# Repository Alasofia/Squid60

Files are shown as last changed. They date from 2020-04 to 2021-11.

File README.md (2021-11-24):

# Squid60
GH60 Compatible PCB using Hi-Tek 725 Series (Space Invaders) switches.

Supports 8255C+/RT101 layouts.

Thanks to Engicoder and ai03 for the footprints and PCB design guide.

# Pictures
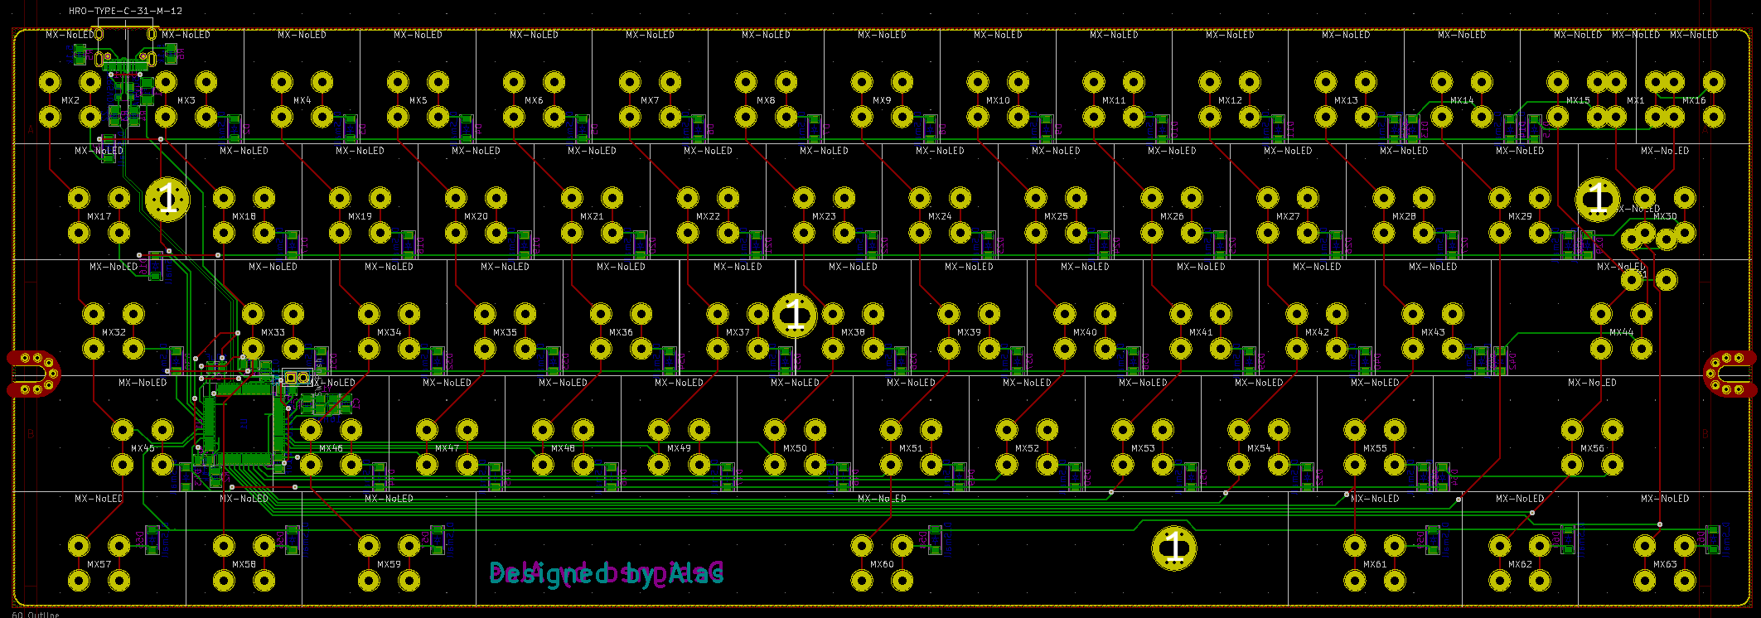
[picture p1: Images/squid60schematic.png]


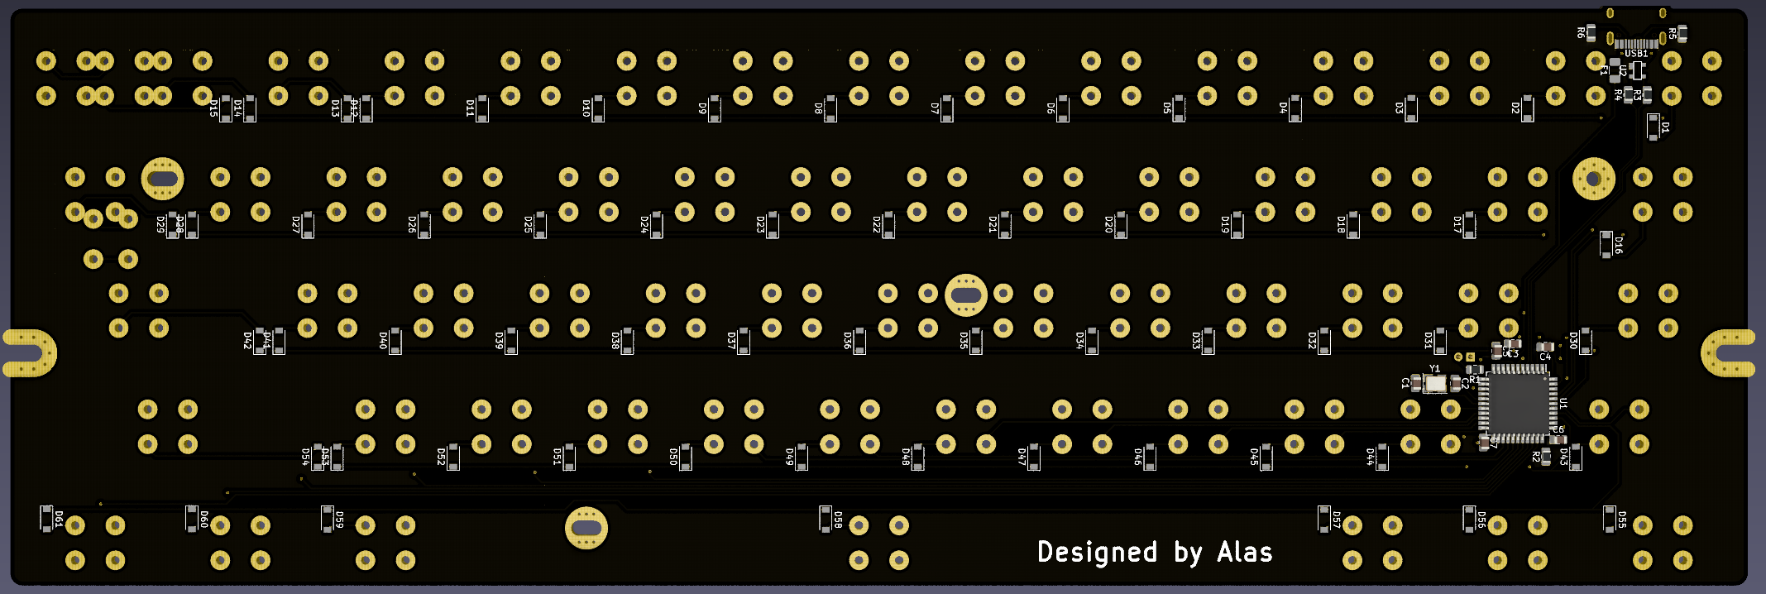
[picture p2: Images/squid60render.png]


This work is licensed under the Creative Commons Attribution-NonCommercial 4.0 International License.

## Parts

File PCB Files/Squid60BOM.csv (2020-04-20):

Id | Designator | Package | Quantity | Designation | Supplier and ref
1 | REF** | 60_Outline-Modded | 1 | 60_Outline
2 | SW1 | PinSocket_1x02_P2.00mm_Vertical | 1 | SW_Push
3 | Y1 | Crystal_SMD_3225-4Pin_3.2x2.5mm | 1 | 16Mhz
4 | F1 | Fuse_1206_3216Metric | 1 | 500mA
5 | C7,C6,C5 | C_0805_2012Metric | 3 | 0.1uF
6 | C4 | C_0805_2012Metric | 1 | 10uF
7 | C3 | C_0805_2012Metric | 1 | 1uF
8 | C2,C1 | C_0805_2012Metric | 2 | 22pF
9 | R6,R5 | R_0805_2012Metric | 2 | 5.1k
10 | R4,R3 | R_0805_2012Metric | 2 | 22
11 | R2 | R_0805_2012Metric | 1 | 1k
12 | R1 | R_0805_2012Metric | 1 | 10k
13 | U1 | TQFP-44_10x10mm_P0.8mm | 1 | ATmega32U4-AU
14 | MX44,MX45 | Hitek725-2.25U | 2 | MX-NoLED
15 | MX63,MX61,MX59,MX57,MX30,MX17 | Hitek725-1.5U | 6 | MX-NoLED
16 | MX62,MX58,MX55,MX54,MX53,MX52,MX51,MX50,MX49,MX48,MX47,MX46,MX43,MX42,MX41,MX40,MX39,MX38,MX37,MX36,MX35,MX34,MX33,MX29,MX28,MX27,MX26,MX25,MX24,MX23,MX22,MX21,MX20,MX19,MX18,MX16,MX15,MX14,MX13,MX12,MX11,MX10,MX9,MX8,MX7,MX6,MX5,MX4,MX3,MX2 | Hitek725-1U | 50 | MX-NoLED
17 | USB1 | HRO-TYPE-C-31-M-12-Assembly | 1 | HRO-TYPE-C-31-M-12
18 | U2 | SOT143B | 1 | PRTR5V0U2X
19 | MX31 | Hitek725-BigAssEnter | 1 | MX-NoLED
20 | MX1 | Hitek725-2U | 1 | MX-NoLED
21 | MX60 | Hitek725-7U | 1 | MX-NoLED
22 | MX56 | Hitek725-2.75U | 1 | MX-NoLED
23 | MX32 | Hitek725-1.75U | 1 | MX-NoLED
24 | D61,D60,D59,D58,D57,D56,D55,D54,D53,D52,D51,D50,D49,D48,D47,D46,D45,D44,D43,D42,D41,D40,D39,D38,D37,D36,D35,D34,D33,D32,D31,D30,D29,D28,D27,D26,D25,D24,D23,D22,D21,D20,D19,D18,D17,D16,D15,D14,D13,D12,D11,D10,D9,D8,D7,D6,D5,D4,D3,D2,D1 | D_SOD-123-Pretty | 61 | D_Small

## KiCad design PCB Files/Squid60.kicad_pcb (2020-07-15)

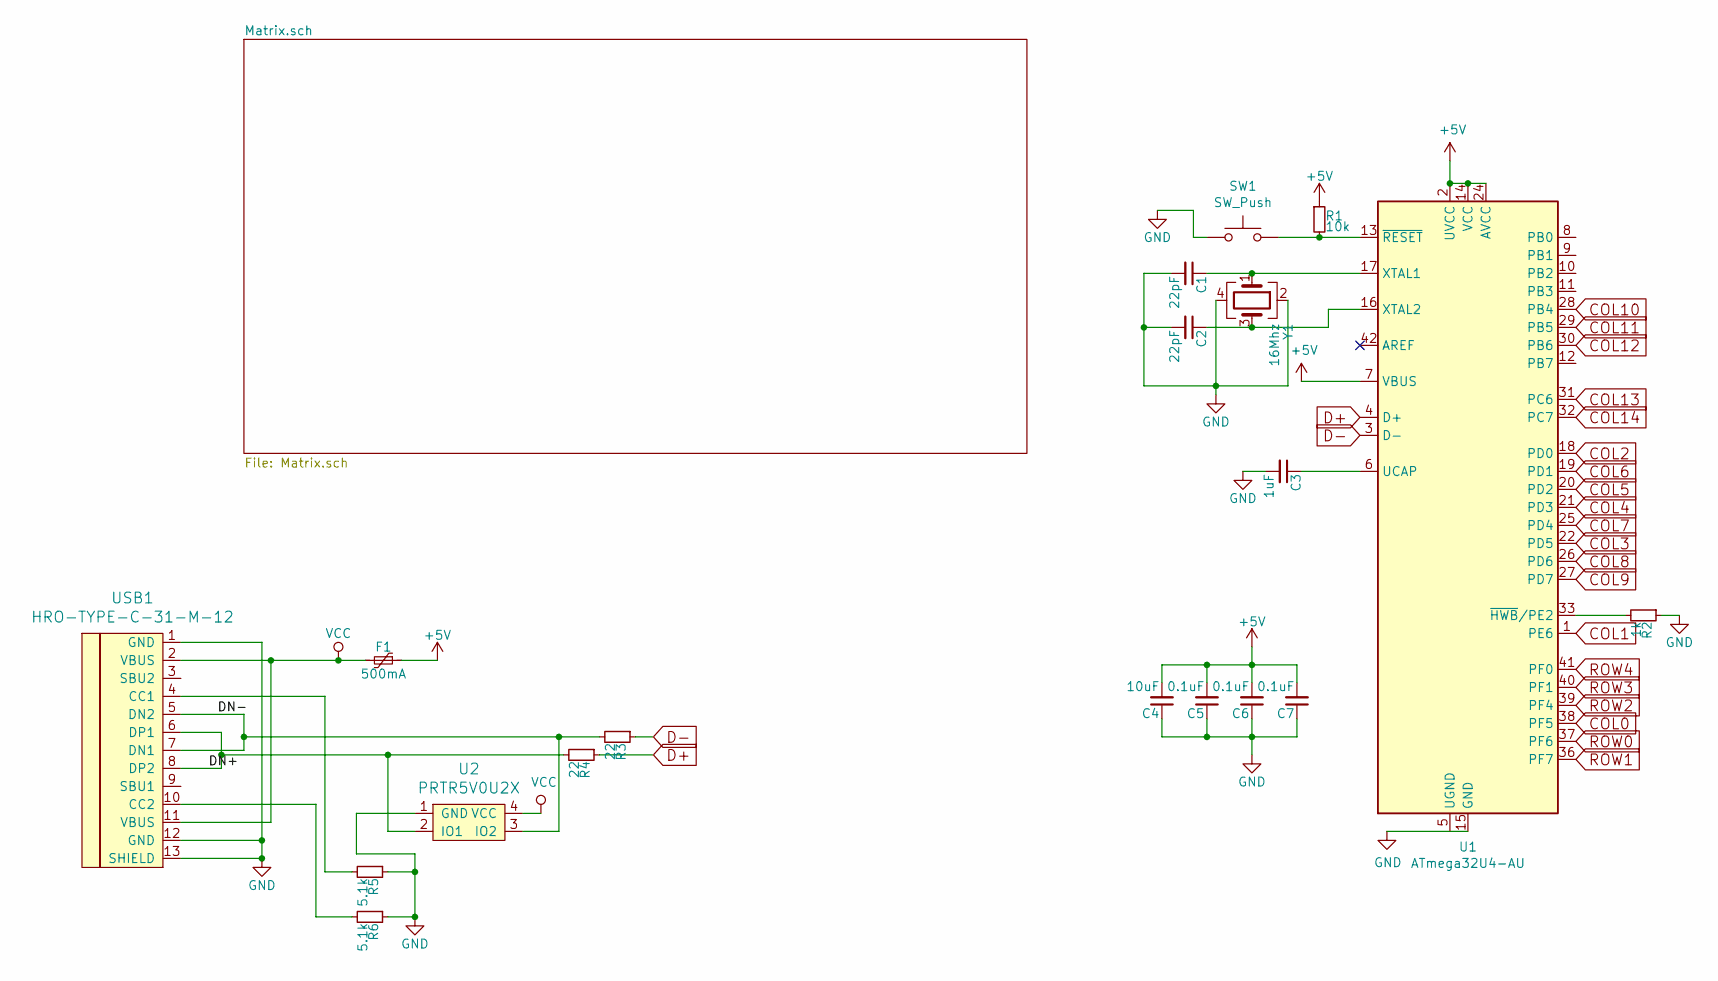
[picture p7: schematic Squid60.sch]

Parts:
C1, C2: 22pF; C_0805_2012Metric
C3: 1uF; C_0805_2012Metric
C4: 10uF; C_0805_2012Metric
C5, C6, C7: 0.1uF; C_0805_2012Metric
F1: 500mA; Fuse_1206_3216Metric
R1: 10k; R_0805_2012Metric
R2: 1k; R_0805_2012Metric
R3, R4: 22; R_0805_2012Metric
R5, R6: 5.1k; R_0805_2012Metric
SW1: SW_Push; PinSocket_1x02_P2.00mm_Vertical
U1: ATmega32U4-AU; TQFP-44_10x10mm_P0.8mm
U2: PRTR5V0U2X; SOT143B
USB1: HRO-TYPE-C-31-M-12; HRO-TYPE-C-31-M-12-Assembly
Y1: 16Mhz; Crystal_SMD_3225-4Pin_3.2x2.5mm

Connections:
+5V: C4.2, C5.2, C6.2, C7.2, F1.1, R1.1, U1.2 (UVCC), U1.7 (VBUS), U1.14 (VCC), U1.24 (AVCC), U1.34 (VCC), U1.44 (AVCC)
/DN+: R4.2, U2.2 (IO1), USB1.6 (DP1), USB1.8 (DP2)
/DN-: R3.2, U2.3 (IO2), USB1.5 (DN2), USB1.7 (DN1)
COL0: U1.38 (PF5); also elsewhere on the board
COL1: U1.1 (PE6); also elsewhere on the board
COL2: U1.18 (PD0); also elsewhere on the board
COL3: U1.22 (PD5); also elsewhere on the board
COL4: U1.21 (PD3); also elsewhere on the board
COL5: U1.20 (PD2); also elsewhere on the board
COL6: U1.19 (PD1); also elsewhere on the board
COL7: U1.25 (PD4); also elsewhere on the board
COL8: U1.26 (PD6); also elsewhere on the board
COL9: U1.27 (PD7); also elsewhere on the board
COL10: U1.28 (PB4); also elsewhere on the board
COL11: U1.29 (PB5); also elsewhere on the board
COL12: U1.30 (PB6); also elsewhere on the board
COL13: U1.31 (PC6); also elsewhere on the board
COL14: U1.32 (PC7); also elsewhere on the board
D+: R4.1, U1.4 (D+)
D-: R3.1, U1.3 (D-)
GND: C1.2, C2.2, C3.2, C4.1, C5.1, C6.1, C7.1, R2.1, R5.1, R6.1, SW1.1, U1.15 (GND), U1.23 (GND), U1.35 (GND), U1.43 (GND), U2.1 (GND), USB1.1 (GND), USB1.12 (GND), USB1.13 (SHIELD), Y1.2, Y1.4
unnamed: C1.1, U1.17 (XTAL1), Y1.1
unnamed: C2.1, U1.16 (XTAL2), Y1.3
unnamed: C3.1, U1.6 (UCAP)
unnamed: R1.2, SW1.2, U1.13 (~RESET)
unnamed: R2.2, U1.33 (~HWB~/PE2)
unnamed: R5.2, USB1.4 (CC1)
unnamed: R6.2, USB1.10 (CC2)
ROW0: U1.37 (PF6); also elsewhere on the board
ROW1: U1.36 (PF7); also elsewhere on the board
ROW2: U1.39 (PF4); also elsewhere on the board
ROW3: U1.40 (PF1); also elsewhere on the board
ROW4: U1.41 (PF0); also elsewhere on the board
VCC: F1.2, U2.4 (VCC), USB1.2 (VBUS), USB1.11 (VBUS)

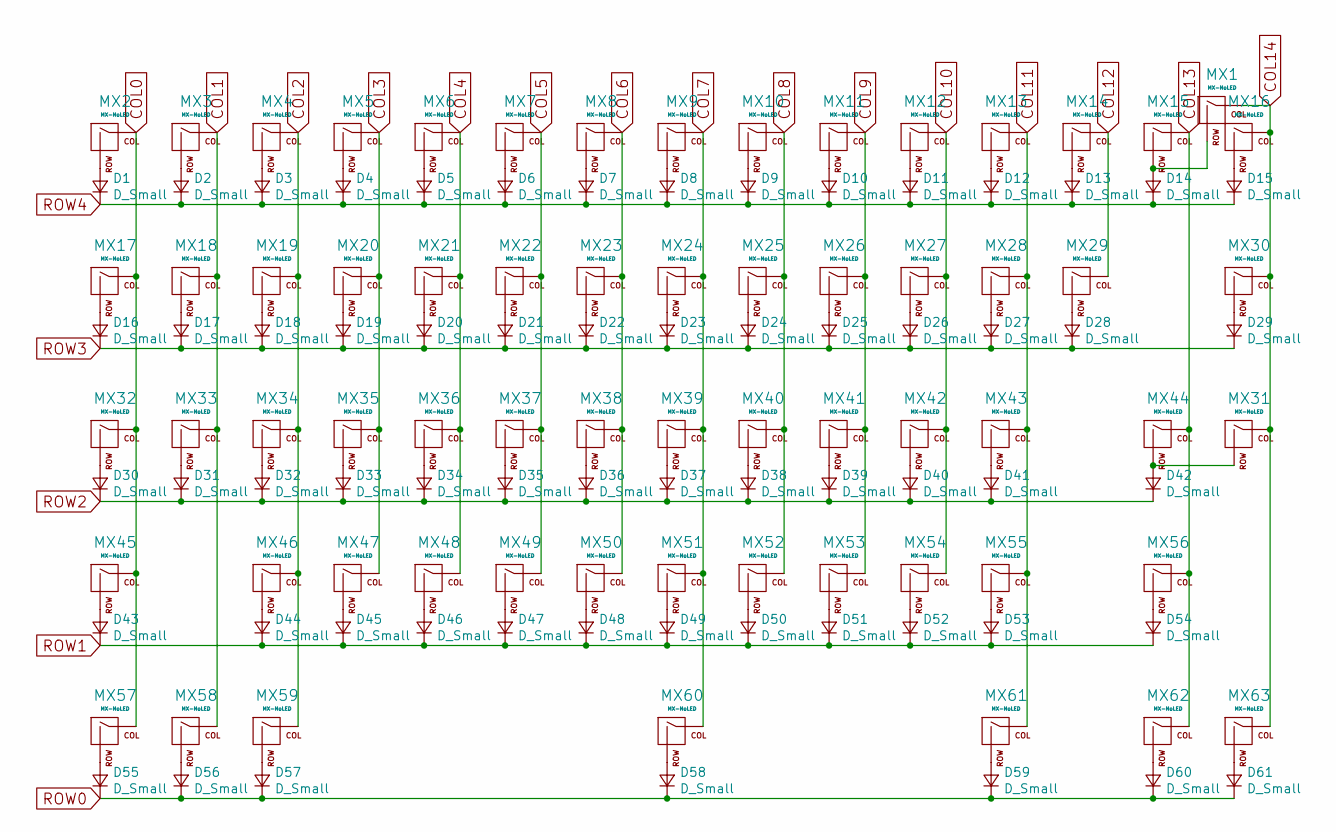
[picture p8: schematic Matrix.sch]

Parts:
D1, D2, D3, D4, D5, D6, D7, D8, D9, D10, D11, D12, D13, D14, D15, D16, D17, D18, D19, D20, D21, D22, D23, D24, D25, D26, D27, D28, D29, D30, D31, D32, D33, D34, D35, D36, D37, D38, D39, D40, D41, D42, D43, D44, D45, D46, D47, D48, D49, D50, D51, D52, D53, D54, D55, D56, D57, D58, D59, D60, D61: D_Small; D_SOD-123-Pretty
MX1: MX-NoLED; Hitek725-2U
MX2, MX3, MX4, MX5, MX6, MX7, MX8, MX9, MX10, MX11, MX12, MX13, MX14, MX15, MX16, MX18, MX19, MX20, MX21, MX22, MX23, MX24, MX25, MX26, MX27, MX28, MX29, MX33, MX34, MX35, MX36, MX37, MX38, MX39, MX40, MX41, MX42, MX43, MX46, MX47, MX48, MX49, MX50, MX51, MX52, MX53, MX54, MX55, MX58, MX62: MX-NoLED; Hitek725-1U
MX17, MX30, MX57, MX59, MX61, MX63: MX-NoLED; Hitek725-1.5U
MX31: MX-NoLED; Hitek725-BigAssEnter
MX32: MX-NoLED; Hitek725-1.75U
MX44, MX45: MX-NoLED; Hitek725-2.25U
MX56: MX-NoLED; Hitek725-2.75U
MX60: MX-NoLED; Hitek725-7U

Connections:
COL0: MX2.1 (COL), MX17.1 (COL), MX32.1 (COL), MX45.1 (COL), MX57.1 (COL); also elsewhere on the board
COL1: MX3.1 (COL), MX18.1 (COL), MX33.1 (COL), MX58.1 (COL); also elsewhere on the board
COL2: MX4.1 (COL), MX19.1 (COL), MX34.1 (COL), MX46.1 (COL), MX59.1 (COL); also elsewhere on the board
COL3: MX5.1 (COL), MX20.1 (COL), MX35.1 (COL), MX47.1 (COL); also elsewhere on the board
COL4: MX6.1 (COL), MX21.1 (COL), MX36.1 (COL), MX48.1 (COL); also elsewhere on the board
COL5: MX7.1 (COL), MX22.1 (COL), MX37.1 (COL), MX49.1 (COL); also elsewhere on the board
COL6: MX8.1 (COL), MX23.1 (COL), MX38.1 (COL), MX50.1 (COL); also elsewhere on the board
COL7: MX9.1 (COL), MX24.1 (COL), MX39.1 (COL), MX51.1 (COL), MX60.1 (COL); also elsewhere on the board
COL8: MX10.1 (COL), MX25.1 (COL), MX40.1 (COL), MX52.1 (COL); also elsewhere on the board
COL9: MX11.1 (COL), MX26.1 (COL), MX41.1 (COL), MX53.1 (COL); also elsewhere on the board
COL10: MX12.1 (COL), MX27.1 (COL), MX42.1 (COL), MX54.1 (COL); also elsewhere on the board
COL11: MX13.1 (COL), MX28.1 (COL), MX43.1 (COL), MX55.1 (COL), MX61.1 (COL); also elsewhere on the board
COL12: MX14.1 (COL), MX29.1 (COL); also elsewhere on the board
COL13: MX15.1 (COL), MX44.1 (COL), MX56.1 (COL), MX62.1 (COL); also elsewhere on the board
COL14: MX1.1 (COL), MX16.1 (COL), MX30.1 (COL), MX31.1 (COL), MX63.1 (COL); also elsewhere on the board
unnamed: D1.2 (A), MX2.2 (ROW)
unnamed: D2.2 (A), MX3.2 (ROW)
unnamed: D3.2 (A), MX4.2 (ROW)
unnamed: D4.2 (A), MX5.2 (ROW)
unnamed: D5.2 (A), MX6.2 (ROW)
unnamed: D6.2 (A), MX7.2 (ROW)
unnamed: D7.2 (A), MX8.2 (ROW)
unnamed: D8.2 (A), MX9.2 (ROW)
unnamed: D9.2 (A), MX10.2 (ROW)
unnamed: D10.2 (A), MX11.2 (ROW)
unnamed: D11.2 (A), MX12.2 (ROW)
unnamed: D12.2 (A), MX13.2 (ROW)
unnamed: D13.2 (A), MX14.2 (ROW)
unnamed: D14.2 (A), MX1.2 (ROW), MX15.2 (ROW)
unnamed: D15.2 (A), MX16.2 (ROW)
unnamed: D16.2 (A), MX17.2 (ROW)
unnamed: D17.2 (A), MX18.2 (ROW)
unnamed: D18.2 (A), MX19.2 (ROW)
unnamed: D19.2 (A), MX20.2 (ROW)
unnamed: D20.2 (A), MX21.2 (ROW)
unnamed: D21.2 (A), MX22.2 (ROW)
unnamed: D22.2 (A), MX23.2 (ROW)
unnamed: D23.2 (A), MX24.2 (ROW)
unnamed: D24.2 (A), MX25.2 (ROW)
unnamed: D25.2 (A), MX26.2 (ROW)
unnamed: D26.2 (A), MX27.2 (ROW)
unnamed: D27.2 (A), MX28.2 (ROW)
unnamed: D28.2 (A), MX29.2 (ROW)
unnamed: D29.2 (A), MX30.2 (ROW)
unnamed: D30.2 (A), MX32.2 (ROW)
unnamed: D31.2 (A), MX33.2 (ROW)
unnamed: D32.2 (A), MX34.2 (ROW)
unnamed: D33.2 (A), MX35.2 (ROW)
unnamed: D34.2 (A), MX36.2 (ROW)
unnamed: D35.2 (A), MX37.2 (ROW)
unnamed: D36.2 (A), MX38.2 (ROW)
unnamed: D37.2 (A), MX39.2 (ROW)
unnamed: D38.2 (A), MX40.2 (ROW)
unnamed: D39.2 (A), MX41.2 (ROW)
unnamed: D40.2 (A), MX42.2 (ROW)
unnamed: D41.2 (A), MX43.2 (ROW)
unnamed: D42.2 (A), MX31.2 (ROW), MX44.2 (ROW)
unnamed: D43.2 (A), MX45.2 (ROW)
unnamed: D44.2 (A), MX46.2 (ROW)
unnamed: D45.2 (A), MX47.2 (ROW)
unnamed: D46.2 (A), MX48.2 (ROW)
unnamed: D47.2 (A), MX49.2 (ROW)
unnamed: D48.2 (A), MX50.2 (ROW)
unnamed: D49.2 (A), MX51.2 (ROW)
unnamed: D50.2 (A), MX52.2 (ROW)
unnamed: D51.2 (A), MX53.2 (ROW)
unnamed: D52.2 (A), MX54.2 (ROW)
unnamed: D53.2 (A), MX55.2 (ROW)
unnamed: D54.2 (A), MX56.2 (ROW)
unnamed: D55.2 (A), MX57.2 (ROW)
unnamed: D56.2 (A), MX58.2 (ROW)
unnamed: D57.2 (A), MX59.2 (ROW)
unnamed: D58.2 (A), MX60.2 (ROW)
unnamed: D59.2 (A), MX61.2 (ROW)
unnamed: D60.2 (A), MX62.2 (ROW)
unnamed: D61.2 (A), MX63.2 (ROW)
ROW0: D55.1 (K), D56.1 (K), D57.1 (K), D58.1 (K), D59.1 (K), D60.1 (K), D61.1 (K); also elsewhere on the board
ROW1: D43.1 (K), D44.1 (K), D45.1 (K), D46.1 (K), D47.1 (K), D48.1 (K), D49.1 (K), D50.1 (K), D51.1 (K), D52.1 (K), D53.1 (K), D54.1 (K); also elsewhere on the board
ROW2: D30.1 (K), D31.1 (K), D32.1 (K), D33.1 (K), D34.1 (K), D35.1 (K), D36.1 (K), D37.1 (K), D38.1 (K), D39.1 (K), D40.1 (K), D41.1 (K), D42.1 (K); also elsewhere on the board
ROW3: D16.1 (K), D17.1 (K), D18.1 (K), D19.1 (K), D20.1 (K), D21.1 (K), D22.1 (K), D23.1 (K), D24.1 (K), D25.1 (K), D26.1 (K), D27.1 (K), D28.1 (K), D29.1 (K); also elsewhere on the board
ROW4: D1.1 (K), D2.1 (K), D3.1 (K), D4.1 (K), D5.1 (K), D6.1 (K), D7.1 (K), D8.1 (K), D9.1 (K), D10.1 (K), D11.1 (K), D12.1 (K), D13.1 (K), D14.1 (K), D15.1 (K); also elsewhere on the board

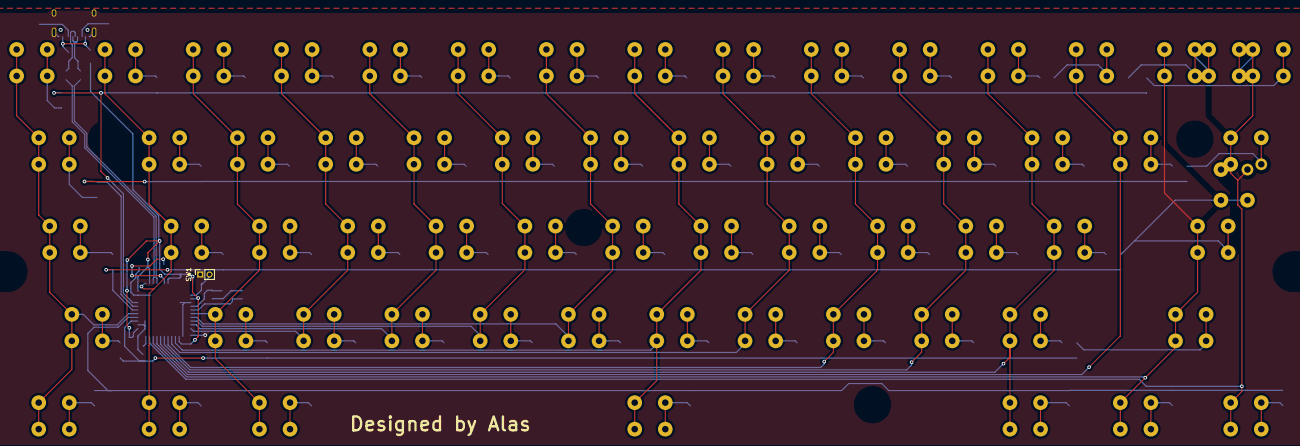
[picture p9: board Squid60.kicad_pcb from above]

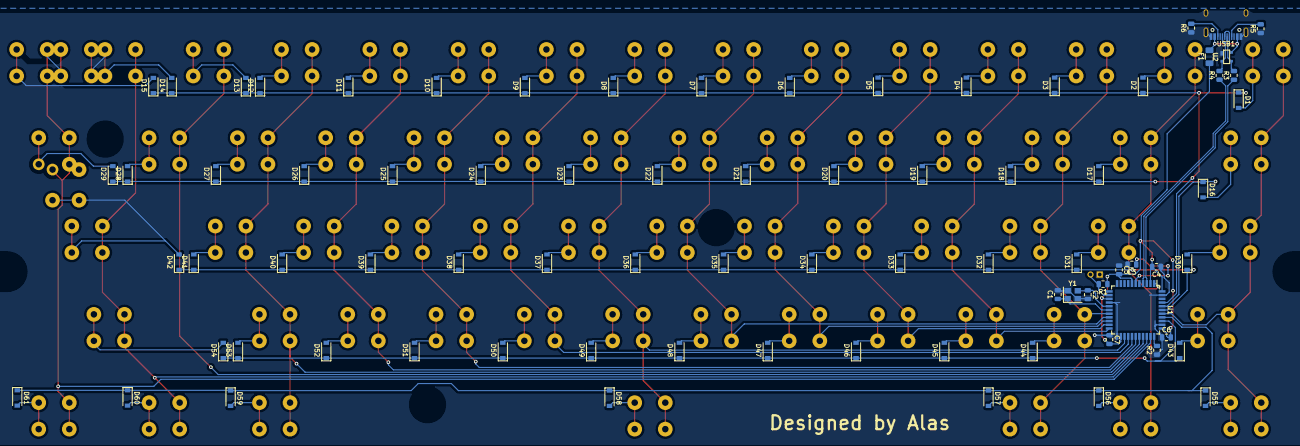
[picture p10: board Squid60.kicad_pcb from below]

Board: 2 copper layers, 143 parts (81 on the bottom side), 95 nets.

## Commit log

2020-04-19 Organization and images
    [Matrix.sch, Squid60.kicad_pcb, Squid60.sch]
2020-04-19 Couple Fixes
    row 3 wasn't routed, row 1 had not been finished
    [Squid60-B_Cu.gbr, Squid60-B_Mask.gbr, Squid60-B_Paste.gbr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]
2020-04-19 Redid Gerbers to reflect last commit
    [Squid60-B_Cu.gbr, Squid60-B_Mask.gbr, Squid60-B_Paste.gbr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]
2020-04-19 Removed Silkscreens
    Because I don't to get sued
    Also redid gerbers for that because again, yikes
    [Squid60-B_Cu.gbr, Squid60-B_Mask.gbr, Squid60-B_Paste.gbr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]
2020-04-20 Updated images in readme
    and updated gerbers to be sure they're correct
    [Squid60-B_Cu.gbr, Squid60-B_Mask.gbr, Squid60-B_Paste.gbr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]
2020-04-20 Ignore previous commit
    I'm dumb, THIS commit fixes those things
    [Squid60-B_Cu.gbr, Squid60-B_Mask.gbr, Squid60-B_Paste.gbr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]
2020-04-25 added fr4 plate files
    [plate.kicad_pcb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]
2020-07-15 Fixed up the overlapping footprints and zipped gerbers
    [Matrix.sch, Squid60.kicad_pcb]
